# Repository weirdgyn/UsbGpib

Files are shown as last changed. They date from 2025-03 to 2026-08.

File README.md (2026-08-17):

# Table of contents

:newspaper: [Latest updates](Updates.md)
<br> :hammer: [Buy it or build it](#buy-it-or-build-it)
<br> :wave: [UsbGpib Introduction](#usbgpib-introduction)
<br> :house: [Housing / Enclosure](#housings)
<br> :computer: [Software](#software)
<br> &nbsp; &nbsp; :electric_plug: [Using the device](#using-the-device)
<br> &nbsp; &nbsp; :gear: [Setting and getting parameters](#setting-parameters)
<br> :heavy_check_mark: [Testing status](#testing-status)
<br> :notebook: [Tutorials](Tutorials/README.md) <- **New!**
<br> :heart: [Support the Project](#support-the-project)

# Summarized latest updates

For detailed visibility look under the Latest update link above!

[17h Aug 2026] Nice project: **[XyphroLabs-USBGpib-DMM4050](https://github.com/ZandanKhan/XyphroLabs-USBGpib-DMM4050)** — a Python GUI by [Zandan Khan](https://github.com/ZandanKhan) for controlling the Tektronix DMM 4050 (6½-digit precision multimeter) over UsbGpib, with measurement logging to CSV. Great example of building a full front-end on top of this adapter.

[17th Aug 2026]: **GPIBee is available, but...**

# GPIBee = UsbGpib V3 is available!

The title says it: GPIBee - UsbGpib V3 - is now available. Finally!  
  
It's for everyone who's told me, in issues and DMs, "I love this, but I don't have time to build one": USB-C and Ethernet with PoE, VXI-11 with multiple simultaneous sessions, and 3.5-5x the speed of V2 - in a proper enclosure, with real support behind it. 
It's built, tested, and shipping now.

I put together a short video showing it in action: [Introducing GPIBee](https://lnkd.in/epR7Xf-b).  
And you can find the full details at [GPIBee.com](https://www.gpibee.com).

This didn't come out of nowhere - there's a bit of a story behind it, including one thing I haven't said outright until now, something I went back and forth on for quite a while before deciding.

~7 years ago I started UsbGpib as a weekend project: An open, MIT-licensed way to talk to GPIB instruments without paying for an $800+ commercial adapter. I never expected it to pick up 642 stars, 82 forks, and end up soldered into home labs, universities, and repair benches around the world. That still means a lot to me, and it's the reason I kept and keep maintaining it for as long as I have.

A fair bit of that maintenance happened on evenings and weekends that would otherwise have gone to family time or just switching off. Nothing dramatic - just the normal trade-off of a side project that grew bigger than expected. Honestly, the part I'll remember most isn't the hours, it's the people: The issues, the emails, the odd late-night message or calls from someone debugging their own build. I've genuinely enjoyed those conversations, and they're a big part of why I kept going.

Along the way I also learned some harder lessons. To be clear, I've always been and are genuinely happy to see people or companies build their own UsbGpib - that's exactly what open source is for. What sat less well with me was seeing unrelated manufacturers turn V2 into a business of their own, selling it at scale with no attribution back to the project. That's a different thing entirely from working with official partners like Elecrow and Binho, who I have a real relationship with and who've supported this project properly.

But it stayed with me while I was figuring out what V3 should be, and it wasn't an easy decision to make.

So here's the thing I haven't said outright until now: V3 - GPIBee - is a commercial product rather than an open one. Something which might change in future, but for now it is.

That's a real change from V1/V2, and I don't want to gloss over it.

Here's the honest reasoning:

- Going commercial means there's a sustainable way to keep this going, rather than relying on whatever spare evenings I happen to have.
- It lets me fund the things a hobby project can't - CNC-machined, EMI-shielded enclosures, firmware QA, and proper support.
- It gives the project a legitimate path forward that undercutting clones can't quietly erase.

None of that changes what's already yours. V1 and V2 stay exactly as they are - MIT-licensed, fully open, schematics and firmware included, free to build and modify. And to be clear: I'm not walking away from it. I'll keep maintaining UsbGpib - answering issues, keeping it working - alongside GPIBee, not instead of it.

I'm proud of where this landed, and I'm looking forward to keeping both projects going - UsbGpib and GPIBee side by side. Thanks for seven years of bug reports and good conversations so far, with plenty more to come I hope. I hope some of you will give GPIBee a look, and either way, I'd genuinely love to hear what you think.

---

# Buy it or build it

* Tired of tinkering? Want to skip the hassle and get straight to using your GPIB setup?  
* You’d rather spend your time using your instruments instead of assembling hardware?

Skip the soldering iron and jump straight into your GPIB workflow!

You’ve got two solid options to get a ready‑to‑run UsbGpib adapter.

## &#x1f1fa;&#x1f1f8; - United States
* If you're in the US, you can now order the UsbGpibV2 directly from several sources, including my distribution partner Binho LLC. Enjoy fast domestic shipping with no long waits, no customs paperwork, and no surprises - just quick delivery and a smooth experience: 
<br> &#x1F449; <a href="https://binho.io/test-measurement/products/usbgpib-v2/" target="_blank">https://binho.io/test-measurement/products/usbgpib-v2/</a>
<br> &#x1F449; <a href="https://www.digikey.com/short/29nqq5cz" target="_blank"> https://www.digikey.com/short/29nqq5cz</a>
<br> &#x1F449; Amazon US also has it listed, but right now no stock, but worthwhile to check it out there too.

## &#x1F30E; - Worldwide
* I’ve teamed up with Elecrow to bring you ready-to-roll GPIB-USB converters – perfect for those who want results, not a weekend project.
* These adapters come fully assembled, programmed, housed, tested, and ready to go. No fuss. No build. Just plug it in and start working.
* The Adapters match 100% the V2 version described in this repository. 
* &#x1F449; <a href="https://www.elecrow.com/xyphrolabs-gpibusb.html" target="_blank">https://www.elecrow.com/xyphrolabs-gpibusb.html</a>

Let the data flow begin!

This doesn’t mean I’m going fully commercial - far from it.
Offering pre-built adapters is simply a convenience for those who’d rather skip the build and get straight to using their gear.

All sharing, support, and collaboration will remain fully open, just as before.
This is about choice, not change!

The full design files are located in this repository in case you want to build the devices yourself.

---

# UsbGpib Introduction
Versatile, cheap, portable and robust USB to GPIB converter (USBTMC class based).

You'll find many projects like this, but this one is special (ok, everybody will claim this) :-)

V1 Hardware: 


V2 Hardware: 


If you have a lot of test equipment at home, you might know the issues: Lots of devices only have GPIB as interface and the GPIB adapters and GPIB cables on the market are very expensive and some of them even have many issues, when run under Windows 10 (device driver does not work). Or they e.g. are not able to be operated with VISA, because they are UART based, need special command sequences, ...


The adapters are also typically very long, such that they extend the overall length of your test equipment by at least 10cm (~4 inches).

Apart of the 2 very big manufacturers, other GPIB adapters, e.g. with Ethernet or also USB interface are not recognized by normal VISA providers or PyVisa, making the measurement control implementation specific for your GPIB adapter.

I've got frustrated and tried to turn it into something positive. Here a video showing the final device in action - click to view:

(https://www.youtube.com/watch?v=pZp1QZCXrF8) 

Some goals of the project were:
- Work based on the standard USBTMC protocol. This allows the GPIB test equipment to look like a normal USB based measurement device and work flawless with e.g. NI VISA, Labview, Matlab or PyVisa.
- Have a small length - otherwise my equipment has the risk of falling from the shelf :-) Also the USB cable should connect 90 degree angled, to make it very short. With V2 HW, the length got further reduced to the size of a GPIB connector.
- It should be cheap but still versatile (you can build a single one of these for only 14 USD!)
- It should support ALL my test equipment, from many different GPIB implementation generations and different GPIB flavors
- The Firmware should be upgradeable over USB
- It should be rock-solid (!) I don't want to end up in a very long measurement being interrupted because of a software issue of my USB GPIB converter.
- It should support additional features like serial poll, remote enabling/disabling
- If there is no GPIB device connected to the USBGpib converter, or the GPIB device is powered down, there should be no USB device visible on the PC.

All those goals are met.

---

# Hardware

## Microcontroller choice

Although I typically would prefer nowadays an ARM Cortex M0/3/4/7 controller, there is an issue with it. Available devices support only max. 3.3V supply voltages, such that there would be a requirement for a level-shifter towards the GPIB Bus.
GPIB is based on 5V (not exactly true, but a first iteration).

This limited the microcontroller choice to e.g. AVR or PIC controllers. Because of very good availability I ended up in ATMEGA32U4 controllers.
Apart of the device supporting 5V I/O voltages, it also does not require a regulator to be part of the application - it has an internal 3.3V regulator. This minimizes the full application schematic and BOM.

Apart from that, there is an excellent USB stack available [http://www.fourwalledcubicle.com/LUFA.php](http://www.fourwalledcubicle.com/LUFA.php).

The GPIB side of the schematic can be directly connected to the ATMega32U4 IO pins. The IO pins from the microcontroller side are only set to 2 different states: Tri-state (input) or output LOW, to talk over GPIB.

## Component sourcing

All components are easy to source, so I only specify the potential critical ones:

- 16 MHz Crystal: Farnell 2853867 - MCSJK-7E-16.00-8-30-100-B-30 
- REV 1 GPIB connector: Farnell 2421095 - NORCOMP 112-024-113R001. For REV 2 use a straight 24P male solder type connector e.g. from AliExpress.
- USB connector for V1 HW: Farnell 2668483 - Amphenol ICC 61729-1011BLF
- USB connector for V2 HW: Best is to look on AliExpress for 57 series 24P connector as a starting point.

## PCB

The PCB can be ordered at nearly any PCB pool production service (e.g. 10 PCBs for 2 USD + shipping). The gerber files are included in the "HW/Gerber files" subdirectory.

## Mounting the PCB & Flashing the firmware

The PCB is available in 2 revisions.
- [REV 1](HW/REV1/README.md) is the most popularly used right now due to age. It has a USB Type-B connector and an L-shaped housing visible on a few photos of this page.
- [REV 2](HW/REV2/README.md) has some improvements like being smaller, better fit and USB Type-C connector.
- A REV 3 is upcoming. It will be a major redesign with more speed, Ethernet and power over Ethernet support, but the same DNA: Standard protocols being used and ensure compatibility and stability!

Choose whatever you prefer. The software images, but also the external behavior is the same.

---

# Housings

## REV 1


I created a sophisticated 3D printable housing for this adapter. The design was made with Fusion 360. The project file + the STL files are included in the "Housing" sub directory.

The PCB fits perfectly into it. Optionally it can be fixed with 2 mounting screws (the GPIB connector has 2 threads, use 2 times 4-40 UNC x 3/8) and the TOP cover snaps onto the housing base.

I printed this using an Ender 5 3D printer with black PLA, 0.15mm layer height, 1mm wall thickness, no support.
Take care, that you rotate the TOP part of the housing by 180 degrees, so that the flat side is located on the printer bed.
Printing works fine, several iterations of the design were made to ensure good printability.
I printed so far 15 housings, without a single fail.

More information on this REV 1 can be found here: [REV 1](HW/REV1/README.md).
Note, that also the programming/build instructions moved to this location.

## REV 2



The REV 2 housing is a lot smaller, but requires 2 screws.
The housing is quite important to be able to connect and disconnect the board without breaking anything. It is key for mechanical stability of the adapter.
When operating the device without housing, take very well care when plugging in and out the board in case the GPIB connector has a very tight fit.

Information on how to build it can be found in the HW/REV 2 folder: [REV 2](HW/REV2/README.md).
Note, that also the programming/build instructions moved to this location.

---

# Software

## Source code

The source code of the Boot loader (slightly modified LUFA MassStorage Boot loader) and the main USBGPIB converter are located in the "SW" subdirectory.
At the time of publication LUFA 170418 release was used, with GCC as compiler.

Note: The Software is compatible with any HW revision in this repository. For REV 1 and REV 2 hardware you don't need different SW images.

## Binaries

For those, that just want to create their own device, I've included the binary output in the "SW/binaries" subdirectory.

---

# Using the device

## USB enumeration

You might be surprised initially, that the device does not show up in your device manager (or lsusb), when you connect only the USB side. This is a feature, not a bug (really!).
Only, if a GPIB device is connected, you can see the device on your PC too.

The reason behind the feature is simple: Instead of having a standard GPIB wiring, where you have a single GPIB controller and lots of GPIB devices interconnected, USBGPIB supports only a direct connection of the USBGPIB device to your measurement device. If you have like me e.g. 14 Instruments you don't want all to show up in the device manager, if the measurement device itself is powered down - you won't anyway be able to communicate with a powered down device.

When USB and the GPIB side is connected, the device enumerates. The USBGPIB device reads out the ID of the instrument and constructs a unique USB Serial number out of it. It is thus easily possible to assiate multiple connected USBGPIB devices with the measurement instrument.

The VISA ressource name is constructed from this USB Serial number. You can identify easily e.g. in NiMax, which device is connected:



If you connect your USBGPIB device afterwards to another GPIB measurement device, it will disconnect and connect with a new serial number string, matching the other GPIB device *IDN? response again.

## GPIB settings on your measurement device

GPIBUSB does probe all GPIB primary addresses (and secondary address 0) for presence of a GPIB Talker/listener. It is thus not required to set a specific GPIB address - GPIBUSB will find it itself.

The only importance setting on the measurement device is, that the GPIB interface is enabled, which is typically the case.

## LED indicator

The LED indicates different states:

LED blinking: The USBGPIB converter is connected to a measurement instrument, it is powered off or its GPIB port is disabled. In this state, the device is also not connected to USB and will not show up in the device manager or lsusb.
LED on: The device is connected to a measurement device and GPIB communication possible. It is also accessible over USB
LED off: The device is not connected over USB, or the PC powered off :-)

## Controlling GPIB devices


As this converter implements the standard USBTMC Test and measurement class, you can control your instrument from ANY of the normal VISA tools. I tried so far R&S VISA and NI Visa, using Python and Matlab to talk to the devices.

# Testing status

This project is actively maintained since more than 6 years and I personally consider it as very stable. It is proven by multiple users to operate on MacOSX, Linux and Windows and measurement equipment from several decades.

In general I take bug reports very serious and want to "fix them all". In case you don't get an answer on-time on items you report in the issues section, please write me: Xyphro@gmail.com. 
I often miss seeing issue reports very quickly, as I don't get an email once they are filed.

## Sucessfully tested measurement equipment:

Below list is equipment I mainly myself tested. Many other users have other measurement equipment proven in use already.

- R&S FSEM30
- R&S SMIQ03
- R&S CMU200
- R&S SMW200A
- R&S FSW
- R&S FSV
- Keithley 199 multimeter
- HP 34401 DMM from different generations / with different FW versions
- HP 3325A synthesizer/frequency generator
- HP 3457A multimeter
- Agilent E4406A VSA transmitter tester
- Tektronix TDS7104 Digital Phosphor Oscilloscope
- HP 8596A spectrum analyzer
- Agilent E3648A dual power supply

A rather incomplete summary of equipment reported to work from users is:
- Keithley S46T
- HP/Agilent/Keysight 34401A of different generations
- HP/Aglient/Keysight 34410A
- Agilent N6700B
- Agilent E4416A
- Agilent 34970
- Keysight E3645A
- Keithley 2230G-30-1
- Keithley 2601A
- Tektronix AFG3102
- Tektronix 3014C
- Rohde & Schwarz SMB 100A
- Agilent E3631A
- ICS 4899GPIB
- TTI QL564TP
- Lecroy LW110
- LeCroy 334A
- LeCroy 354A
- Hameg 3524
- Fluke 5522A
- Fluke 5500A 
- and many more... It will take quite a while till I have parsed all my emails for working instruments :-)

## Scenarious

- It works under all popular operating systems like Windows 7 and 10, 11, Linux and MacOSX
- USB1.1, USB2.0 and USB3.x ports tested, with and without USB HUB in between.
- The connection stays responsive, when power cycling the PC, or hibernating/sleeping it
- Different connection cycles (GPIB side connected first, USB side connected first, swapping GPIB side equipment, ...)
- Extensive testing of timeout scenarious. E.g. making an illegal query and testing, if the USBTMC handles the timeouts properly. This was a very tricky part to get right.
- Tested special transfer modes. E.g. capturing screenshots from different equipment is usually something, which will drive other GPIB adapters to the limits, because binary data of unknown length needs to be transported successfully.

# Setting Parameters

The firmware version from 13th January 2024 onwards has the ability for human readable text base configuration of several parameters.
The previous methods are still supported, but won't be further documented. You can look them back in the history of this file.

The command parser is quite simple. For that reason follow the exact syntax as shown below. 
Don't add extra spaces or make other modifications or concatenate commands.

## Read termination method

While most GPIB interfaces use the hardware signal EOI to signal the end of a message, not all old equipment supports it. Some older instruments even don't have the EOI pin hardware wise wired and use \r or \n termination.

The USB-TMC standard allows to set the read termination. While in firmware versions before < 2.0 I did not enable that method, it is now finally supported with standard compliance.

I document here the older method (using pulse indicator request), but I add also the newer methods which are 100% UsbTmc compliant and portable across different equipments. You can choose which ones to use, but in some cases pulse indicator requests can be difficult to issue, for which reason it is likely better to use the standard compliant method.

### Set read termination to CR (\r):
(old method)
```
dev.control_in(0xa1, 0x40, 0, 0, 1); # USBTMC pulse indicator request (enables internal command processing)
dev.write('!term cr')
```
Above setting is volatile. To make this a permanent setting call the below mentioned "!term store" command.

(prefered method) Alternatively you can set the termination directly with visa means, e.g. using PyVisa:
```
dev.set_visa_attribute(visa.constants.VI_ATTR_TERMCHAR_EN, True)
dev.set_visa_attribute(visa.constants.VI_ATTR_TERMCHAR, ord('\r') )
```

### Set read termination to LF (\n):
(old method)
```
dev.control_in(0xa1, 0x40, 0, 0, 1); # USBTMC pulse indicator request (enables internal command processing)
dev.write('!term lf')
```
Above setting is volatile. To make this a permanent setting call the below mentioned "!term store" command.

(prefered method) Alternatively you can set the termination directly with visa means, e.g. using PyVisa:
```
dev.set_visa_attribute(visa.constants.VI_ATTR_TERMCHAR_EN, True)
dev.set_visa_attribute(visa.constants.VI_ATTR_TERMCHAR, ord('\n') )
```

### Set read termination to EOI only (default setting):
(old method) 
```
dev.control_in(0xa1, 0x40, 0, 0, 1); # USBTMC pulse indicator request (enables internal command processing)
dev.write('!term eoi')
```
Above setting is volatile. To make this a permanent setting call the below mentioned "!term store" command.

(prefered method) Alternatively you can set the termination directly with visa means, e.g. using PyVisa:
```
dev.set_visa_attribute(visa.constants.VI_ATTR_TERMCHAR_EN, False)
dev.set_visa_attribute(visa.constants.VI_ATTR_TERMCHAR, ord('\0') )
```

### Save readtermination setting in eeprom (make them non-volatile)
```
dev.control_in(0xa1, 0x40, 0, 0, 1); # USBTMC pulse indicator request (enables internal command processing)
dev.write('!term store')
```

Above relates to the "old non prefered method". In general it is a good idea to set the read termination volatile and use the above suggested methods highlighted with (prefered method).

### Query current termination setting from device
```
dev.control_in(0xa1, 0x40, 0, 0, 1); # USBTMC pulse indicator request (enables internal command processing)
print(dev.query('!term?'))
```
This returns a text string containing "lf", "cr" or "eoi"

## Multi-device support - Setting the GPIB device target address

Since Firmware version V2.4 USBGpib allows supporting multiple instruments.

While the USBTMC protocol allows only setting a single device to be addressed and composite USB devices are not well supported by all VISA implementations, I decided to add a command to set the address of the GPIB device which is addressed.

There is a minor limitation of this approach, which is that service request SRQ handling is only done properly to the currently selected GPIB device.
Another one is, that users shall never forget to set the GPIB address to the correct setting before issuing a command.

### Setting a primary address only

Substitute the text <Primary_address> with a number from 1 to 30 to set the primary address of the new GPIB device to talk to in following GPIB transactions

```
dev.control_in(0xa1, 0x40, 0, 0, 1);
dev.write('!addr <Primary_address>')
```

### Setting a primary + secondary address

Substitute the text <Primary_address> with a number from 1 to 30 to set the primary address and <Secondary_address> with a number from 0..6 or 96..102 of the new GPIB device to talk to in following GPIB transactions.
Note, that not the full subaddress range of 0..31 or 96..127 is supported as of now - this requires a bit more work. Most common device with subaddresses like R&S CMU200 only are well covered with that current range.

```
dev.control_in(0xa1, 0x40, 0, 0, 1);
dev.write('!addr <Primary_address> <Secondary_address>')
```
### Python wrapper example code for GPIB address setting

```
import pyvisa as visa
dev = 'USB0::0x03EB::0x2065::GPIB_22_14236333938351C00011::INSTR'
rm = visa.ResourceManager()
dev = rm.open_resource(dev, open_timeout=1000)

def set_gpib_addr(primary_address, secondary_address = None):
    dev.control_in(0xa1, 0x40, 0, 0, 1);
    if secondary_address is None:
        dev.write('!addr %d' % primary_address);
    else:
        dev.write('!addr %d %d' % (primary_address, secondary_address));
    
# Address CMU200, which is for me on primary address 1, secondary address 0
set_gpib_addr(1, 0)
print(dev.query('*IDN?'))

# address HP3457A on primary GPIB address 22
set_gpib_addr(22)
dev.write('END,ALWAYS')
print(dev.query('ID?'))
```

This code results in my current testsetup with CMU200 and HP3457A in this output:

```
Rohde&Schwarz,CMU 200-1100.0008.02,xxxxxx,V5.22

HP3457A
```

## AutoID setting

Default wise the GPIB adapter tries during power on of the instrument to query using *IDN? or ID? commands the instrument name automatically.
This is used to build the USB serial number, which finally gets part of the VISA ressource string.

Not all instruments support this *IDN / ID? query. For this reason this feature can be turned off.
The serial number will then be built based on the GPIB address of the instrument.

### Turn AutoID feature off
```
dev.control_in(0xa1, 0x40, 0, 0, 1); # USBTMC pulse indicator request (enables internal command processing)
dev.write('!autoid off')
```
This setting is stored in eeprom = non volatile memory, so will survive a power cycle

### Turn AutoID feature on
```
dev.control_in(0xa1, 0x40, 0, 0, 1); # USBTMC pulse indicator request (enables internal command processing)
dev.write('!autoid on')
```
This setting is stored in eeprom = non volatile memory, so will survive a power cycle

### turn auto ID on with delay

Some instruments need after turn on some seconds before GPIB is responsive.

With below 3 settings you can set a delay which is applied before the instrument ID is queried after power on.
Note that it will take then also more time, before the USB device is recognized by the PC.

Also this setting is non-volatile.

Delay 5 seconds:
```
dev.control_in(0xa1, 0x40, 0, 0, 1); # USBTMC pulse indicator request (enables internal command processing)
dev.write('!autoid slow')
```

Delay 15 seconds:
```
dev.control_in(0xa1, 0x40, 0, 0, 1); # USBTMC pulse indicator request (enables internal command processing)
dev.write('!autoid slower')
```

Delay 30 seconds:
```
dev.control_in(0xa1, 0x40, 0, 0, 1); # USBTMC pulse indicator request (enables internal command processing)
dev.write('!autoid slowest')
```

### read autoid setting

```
dev.control_in(0xa1, 0x40, 0, 0, 1); # 
print(dev.query('!autoid?'))
```
Returns as text string either: "off", "on", "slow", "slower" or "slowest".

## Firmware version

Finally I implemented a command to query the USB adapters firmware version :-)

```
dev.control_in(0xa1, 0x40, 0, 0, 1); # USBTMC pulse indicator request (enables internal command processing)
print(dev.query('!ver?'))
```

## Shorten ressource strings (Matlab)

A user discovered that Matlab has a limitation in the VISA ressource string length and shared a pull request to reduce the length.
I expose this now first time in the baseline firmware with the following options.

This setting is stored in eeprom = non volatile.

### Limit the USB serial number to a length of 20 characters
```
dev.control_in(0xa1, 0x40, 0, 0, 1); # USBTMC pulse indicator request (enables internal command processing)
dev.write('!string short')
```

### disable limitation of USB serial number length (default behavior)
```
dev.control_in(0xa1, 0x40, 0, 0, 1); # USBTMC pulse indicator request (enables internal command processing)
dev.write('!string normal')
```

### query the string length setting.
```
dev.control_in(0xa1, 0x40, 0, 0, 1); # USBTMC pulse indicator request (enables internal command processing)
print(dev.query('!string?'))
```

This returns as text string either "normal" or "short".

## reset the adapter
```
dev.control_in(0xa1, 0x40, 0, 0, 1); 
dev.write('!reset')
```

Do a reset of the adapter. Note that due to the reset you have to close the visa session and start a new one as the device re-enumerates on the USB.

---

# Support the project



Or support by buying a fully prebuilt adapter at: <a href="https://www.elecrow.com/xyphrolabs-gpibusb.html" target="_blank">https://www.elecrow.com/xyphrolabs-gpibusb.html</a>

In general any email, post or feedback is also very valuable, and don't feel bad if you don't use the support options :-)
Feel free to contact me at Xyphro@gmail.com

---

This page is from XyphroLabs UsbGpib project: <a href="https://github.com/xyphro/UsbGpib" target="_blank">https://github.com/xyphro/UsbGpib</a>

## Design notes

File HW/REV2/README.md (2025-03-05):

# xyphro UsbGpib HW REV 2

The new HW revision picks up some things that I and other misliked:
- The REV 1 HW - when put beeing assembled into its housing did have change to colide with parts of the instruments body. Especially for Keysight equipment. This new HW revision follows the formfactor of an original GPIB cable to get rid of this mechanical constraint.
- The REV 1 HW required to enter the bootloader with a tweezer. REV 2 has a button. Hold it a few seconds and the bootloader is entered.

The [software](../../SW) will always stay the same, no matter if REV1 or REV 2.

I have built many of those adapters myself so far and have developed trust in the design:


## Assembly process

All files related to HW are located in this folder. Gerber file, BOM, Kicad design files.

## preparing the PCB

Mount only the SMD components. This means: DON'T mount the GPIB connector yet.

On edge you can find a mounting point for a pinheader - 45 degrees angled. Mount 2-3 pin pinheaders here and you now have a 6 pin ISP programming port with standard pinout for your favorit AVR programmer.
Program the bootloader. Pin 1 is marked on the PCB to allow you connecting the ISP cable in the correct orientation.

### Flashing the Microcontroller first time

For initial programming an AVR ISP adapter is needed to program the "Bootloader.hex" file.

It is very important, that the Fuses of the AVR are programmed.

Here an example how to program the bootloader using avrdude (using usbasp programmer):
```
avrdude -c usbasp -p m32u4 -e -Ulock:w:0xFF:m -Uefuse:w:0xcb:m -Uhfuse:w:0xd8:m -Ulfuse:w:0xde:m
avrdude -c usbasp -p m32u4 -U flash:w:BootLoader.hex
```
To program bootloader and application image at the same time using AvrDude, you can use this command:
```
avrdude -c usbasp -p m32u4 -e -Ulock:w:0x3F:m -Uefuse:w:0xcb:m -Uhfuse:w:0xd8:m -Ulfuse:w:0xde:m -U flash:w:TestAndMeasurement.hex -U flash:w:BootLoader.hex
```
Note, that some programmers use a quite high clock frequency on the programming interface. In case of failures try to decrease the SCK clock frequency!

After programming the file, disconnect and connect the device and a USB drive will show up. Copy the TestAndMeasurement.bin file to this USB drive - ideally using the command line. Example: `copy TestAndMeasurement.bin F:\FLASH.BIN`.
On Linux, there is a bug with the LUFA mass storage that means it is required to use `dd if=TestAndMeasurement.bin of=/mnt/FLASH.BIN bs=512 conv=notrunc oflag=direct,sync`.

When done, disconnect USB.

It is now safe to desolder the ISP pinheaders such that the PCB fits into the housing. 
Any further update can happen over USB using the bootloader.

## Building the whole thing together
Preparation:
- Mount the PCB EXCLUDING the GPIB connector.
- Print the housings located in [this folder](../../Housing/Rev2). I print them using 1mm bottom/top/wall thickness, 0.16mm layer height and 30% infil. On my K1 printer it takes 23 minutes to print, on my Ender 5 2.2 hours.
- get 2 20mm M3 screws and 2 M3 nuts
- get a GPIB connector "24P Male solder type" from e.g. Aliexpress

If you have everything in place and prepared, insert the PCB including the GPIB connector (unsoldered!) into the bigger part of the housing:



Then solder 2 pins of the GPIB connector and take the PCB out of the housing again to solder all pins.
(This step is required to ensure that the GPIB connector has the right distance to the PCB and fit into the housing)

As a next step insert the PCB into the big part of the housing again. It has a relatively tight fit - to ensure mechanic stability.

Then put the smaller part of the housing on top of it, insert the screws (they can be pushed hard to destroy the "membrane" first time) and nuts and screw it together.

Voilà... your adapter is finished and ready to use :-)



# Updating the firmware at later stages

To enter the boot loader at later stages for updates, press the button (bigger hole in the housing) using a pen/paperclip for about 3 seconds. Then a USB mass storage (flash drive) enumerates on the PC where the firmware image can be copied too (see previous chapter).

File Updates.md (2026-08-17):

This new file will in future contain all updates. The latest updates are always on top.

# Recent Updates

## 17th Aug 2026

UsbGPIB V3 = GPIBee is available - see: https://www.gpibee.com/

Have also a look at this nice project:  
**[XyphroLabs-USBGpib-DMM4050](https://github.com/ZandanKhan/XyphroLabs-USBGpib-DMM4050)** — a Python GUI by [Zandan Khan](https://github.com/ZandanKhan) for controlling the Tektronix DMM 4050 (6½-digit precision multimeter) over UsbGpib, with measurement logging to CSV. Great example of building a full front-end on top of this adapter.

## 09th June 2026

Devin (W6DVN) has successfully ported the popular KE5FX GPIB Toolkit to work seamlessly with UsbGpib V2. You can find the updated version here: https://github.com/fehknt/GPIB

KE5FX GPIB toolkit is a popular set of specialized GPIB applications created by John Miles to make research-grade measurements using oscilloscopes, spectrum analyzers, counters and other IEEE-488 instruments.

## 18th April 2026

USBGpib has now support to address multiple GPIB devices with the newly added firmware version V2.4.

Similar to some UART based GPIB controllers a command is added to set the GPIB address of the device to talk to.

Look for "Multi‑device support" in [README.md](README.md) for more details and instructions.

## Multi-device support - Setting the GPIB device target address

## 07th March 2026

Chinese New year struck in and just shortly before it UsbGPIB V2 ran out of stock. Fortunately it is now back in stock and ready to order again!

## 04th February 2026

The PDF manuals are now also available in Markdown, generated automatically from the same source as the PDF document. This makes the documentation easier to browse, diff, and maintain in version control, while ensuring both formats stay perfectly in sync. -> See [Tutorials](Tutorials/README.md) section.

Furthermore I am releasing Firmware version V2.3. 
Changes:
- It turned out that Keysight Visa in certain versions can crash when a USBTMC device has a serialnumber with double underscore characters. Note, that the USBTMC standard does not disallow for double underscores. The AutoID function can return double underscores for some instruments - illegal characters returned by *IDN? query get replaced by underscores, so with 2 illegal characters you get double underscores as serial number = visa ressource name. I've now included a filter now to suppress double underscores when autoid is enabled.
- I've fixed Issues #96 and #97 reported by user thewon86. Those were USBTMC protocol issues which were never uncovered or effects seen so far, however the implementation was indeed incorrect here.

I updated also slightly the V3 announcement in the main README.MD. Basically: Firmware is ready for betatesting, Hardware arriving soon and gets distributed immediately once it arrives (@Betatesters: You'll get mail before shipping)!

My US distribution partner <a href="https://binho.io/" target="_blank">binho</a> also added UsbGPIB directly to their webshop (<a href="https://binho.io/test-measurement/products/usbgpib-v2/" target="_blank">https://binho.io/test-measurement/products/usbgpib-v2/</a>). This is ideal for US-market: Devices ship directly from San Francisco and are available for a good price! Checkout also their offerings on Host adapters and PCBite!

## 30th December 2025

Updated the "Buy it or build it section" and added a Digikey US link for buying the adapter.

## 30th November 2025

**Just released a new firmware after testing - version 2.2.**

Changes:
* Read termination related:
  * When the "USBTMC native" method to set the termination was once enabled, disabling it did not have effect anymore - it stayed enabled. Only power cycling got it out of that enabled state. Fixed and tested now.
  * Only \n \r and EOI only were supported read terminations. However, as reported in <a href="https://github.com/xyphro/UsbGpib/issues/85" target="_blank">issue 85</a>, there is quite a number of measurement equipment which requires e.g. ETX (0x03) read termination.  
  I removed now this artificial limitation for read termination, such that any read termination character can be set. From 0x00 to 0xff all codes are supported now.  
  For the eeprom non-volatile based method only \r \n and eoi only options are available and there is no plan to extend it to any termination character as this eeprom based method will also get retired for the upcoming V3 UsbGpib adapter.
* GotoLocal synchronization. USBTMC uses 2 different transfer methods for transfering certain types of messages. Control transfers and Bulk transfers. When e.g. sending a USBTMC command like Reading data which uses Bulk transfers followed by another one like GotoLocal which uses control transfers it is important that they also get executed in that order.   
This is something I took deep care off already since long time for other other control transfers, however as it turned out never tested for GoToLocal.   
And things that are not tested don't work, right?   
Michael discovered this during porting of his <a href="https://github.com/VK2BEA/HP8753-Companion" target="_blank">HP8753-Companion</a> to support the UsbGpib V2 adapter which led to me releasing V2.1 to him a while ago.

The issue is fixed now and confirmed working. This V2.2 includes the 2 additional improvements now.

Next release is planned to cover some good improvements I got suggested on AutoID handling.

## 23rd November 2025

I just finalized a user manual for the UsbGPIB V2 adapter, checkout [Tutorials](Tutorials/README.md) section.

In case you miss certain aspects and want me to add them, let me know (Discussion section, Issue section or email to xyphro@gmail.com)

## From Bench to Ready: Buy It, Plug It, Use It!

Tired of tinkering? Want to skip the hassle and get straight to using your GPIB setup?
* I’ve teamed up with Elecrow to bring you ready-to-roll GPIB-USB converters – perfect for those who want results, not a weekend project.
* These adapters come fully assembled, programmed, housed, tested, and ready to go. No fuss. No build. Just plug it in and start working.
* The Adapters match 100% the V2 version described in this repository. 

**Grab yours now:** <a href="https://www.elecrow.com/xyphrolabs-gpibusb.html" target="_blank">https://www.elecrow.com/xyphrolabs-gpibusb.html</a>

Let the data flow begin!

This doesn’t mean I’m going fully commercial - far from it.
Offering pre-built adapters is simply a convenience for those who’d rather skip the build and get straight to using their gear.

All sharing, support, and collaboration will remain fully open, just as before.
This is about choice, not change!

## Coming soon: Native Linux-Gpib support
<small>(Or actually: It's already there!)</small>

A contact with the Linux-Gpib maintainer resulted in a great cooperation with good outcome. We managed to jointly get native linux-gpib support up and alive. Thanks a lot for that, Dave!

We’ve successfully brought full Linux-GPIB compatibility to life. To enable it, you’ll need to flash a dedicated firmware image:  
- File "LinuxGpib.bin" in sub-folder [LinuxGpib firmware](SW/binaries/) will enable it from firmware perspective. Note: This will make the adapter stop from enumerating as normal usbtmc device (you can reflash the normal firmware again later if you like). The upcoming adapter announced a few days ago will have a combined firmware, but the flash of AtMega32U4 was simply "too full".

Stay tuned — I’ll be publishing a detailed guide soon, covering setup instructions and the powerful benefits of going native on Linux.

Just to avoid misunderstandings: The Adapter always worked under Linux as normal UsbTmc device as it does on any other operating system, but was not supported by the Linux-GPIB library so far. So software packages using linux-GPIB can be used without modification in future.

Would btw. love to get similar integration also in Visa Libraries - let's see what time will bring :-)

## Update on Beta Tester program on new upcoming "V3" Adapter with Ethernet+PoE + High speed USB

I managed to find a decent amount of betatesters for the new upcoming HW. Much more as the originally anticipated 3 persons. Thanks a lot for all who volunteered! 



<small>Status: From the HW side the Ethernet and PoE section is tested successfully. USB was already enabled since long time.
SW side: The USB functionality is fully implemented and first stress testing shows positive results with no lockups. The Ethernet stack is up and running too, but further implementation and testing work is still to be done.</small>

# 21st April '25 update

Today it's time for another release - version V2.0. 

While writing this and looking at this readme.md file, I certainly think that I should clean it up in future - it is not well structured for new users. Sorry for this, but I have this on my radar and will improve. Whenever I have more time I will also extend it with usage examples / small "trainings", especially for those who are completely new to GPIB and controlling instruments.

I had btw. some occasions where users had issues flashing the device. Many of them were caused by the fact that the .hex and .bin files were saved over the GitHub web interface by rightclicking and selecting "Save as". This will result in a HTML page being saved which will not flash well :-)
The safest option is to do a git clone or to download this whole github repository as .zip file.

Here the release V2.0 details:
- **Bugfix:** the options autoid slower and autoid slowest did not work. This is addressed and I test those settings now also properly in release testing, promised :-) The issue was caused in my super slim parser implementation for custom internal commands and "autoid slow" and "autoid slower" start with the same letters causing hickups.
The Windows GUI is also updated to expose those 2 autoid settings - they were not included before.
As general good recommendation, I still recommend to turn autoid feature off, as it limits the measurement instruments which are used - Instruments HAVE to support *IDN? query for it to work well, which is for many old equipment not the case and for such old equipment errors will be flagged after the instrument is turned on.
- **New feature:** I enabled a new method to set the READ termination. One that is fully compliant with usbtmc standard and does not need a workaround with pulse indicator requests. I don't know why I did not spot this earlier, but a discussion with the usbtmc linux kernel mode driver maintainer exposed this to me. When using direct access to usbtmc kernel mode driver you can use the <a href="https://github.com/dpenkler/linux-usbtmc?tab=readme-ov-file#ioctl-to-control-setting-eom-bit" target="_blank">USBTMC_IOCTL_EOM_ENABLE</a> IOCTL to set the read termination. When using a VISA layer, you can set the read termination by setting the VI_ATTR_TERMCHAR_EN and VI_ATTR_TERMCHAR attributes (see below for more details). 
The previous method of setting read termination is not modified in any way, this just gives an additional method to set the readtermination.
- **Bugfix / Improvement:** The pulse indicator request function did use a blocking delay to pulse the LED. This delayed USB side handling. In some cases this could trigger timeouts. The LED blinking is now handled fully asynchronous and those timeouts will not occur anymore.

# 6th April '25 update

Time to release a bugfix (reported by rapgenic #80): V1.9 of the firmware fixes an issue where the "autoid slow" setting was not applied properly.

# 12th January '25 update

## New Gui available! (Windows)

I implemented a small GUI to change the non-volatile settings of the GpibUSB adapter. Sorry - it's windows only :-)
It is a single .exe file without external dependencies. You can just download it, run it and immediately change settings.



Please download it from this folder: [SW/UsbGpibGUI](SW/UsbGpibGUI)

The source code is included in the src sub-directory.

## Python GUI (Linux)

UsbGpib user Jim Houston created an impressive pure Python GUI similar to mine - and I believe he began working on it even before I released mine. His GUI stands out for its versatility and platform independence, requiring only Python to run. It can be executed directly with Python 3 and should run on most platforms.

For details about it, have a look into this discussion thread: [https://github.com/xyphro/UsbGpib/discussions/55](https://github.com/xyphro/UsbGpib/discussions/55)

The GUI can be found here including documentation: [SW/NiceGUI](SW/NiceGUI)

## New Firmware

I release also herewith Version 1.8 of the firmware. 
Mainly a bug-fix was done, that the string setting now also returns short, when it is actually set to short. (issue report #59).

# 13th January '24 update

New year, new update :-)

I realized a user suggestion, which is a better human readable interface to the internal instrument settings.
This also exposes new functionality, e.g. shortening of the visa resource string, adjustable delayed application of AutoID featured, ...
The read termination setting can now be set in a volatile way and also be read back.

A slight issue sneaked in also and got fixed: After an instrument clear the next GPIB transfer timed out. Nobody found it so far though :-) But I fixed it.

Have fun using this!
(would anybody volunteers to make a simple cross platform gui for the non volatile settings :-) ?)

# 19th December '23 update

Finally I made it - the new HW design is on this page. As I had to restructure the repository a bit it took quite a while.
The software image is always the same and runs on both HW revisions.



I also have put a binary for a new Firmware image in there. I am still busy optimizing certain things but want to give you a try before doing a next release.
Please if you test it: Feed it back to me - does it work / does it break anything -> sharing is caring. 

Mail me at xyphro@gmail.com or raise an issue under the issue section.

[FW image location: SW/binaries](SW/binaries)

- 488.2 support further rolled out. This means Status bytes are automatically read out and reported via interrupt transfers to PC as foreseen in the standard.
- FASTER (!) 7 x write speed improvement and 4.x times read speed improvement. As reference: On an FSW I get 310kBytes/s as write transfer speed and 240kBytes/s as read transfer speed.
- a fix for read status byte readout leading to issues on my CMU200
- several smaller race conditions identified and fixed. A lot of work went into stress testing 488.2.

As said, I feel this is the best Firmware image so far, but I changed so much that I want to go first for this small beta test phase asking you explicitly for positive and negative feedback.

---

This page is from XyphroLabs UsbGpib project: <a href="https://github.com/xyphro/UsbGpib" target="_blank">https://github.com/xyphro/UsbGpib</a>

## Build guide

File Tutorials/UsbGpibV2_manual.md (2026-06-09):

- [XyphroLabs UsbGpib V2 User
  Manual](#xyphrolabs-usbgpib-v2-user-manual)
- [Introduction](#introduction)
- [Advantages of UsbGpib V2 adapter](#advantages-of-usbgpib-v2-adapter)
- [Safety Precautions](#safety-precautions)
  - [Operating Conditions](#operating-conditions)
  - [Storage Conditions](#storage-conditions)
  - [Moisture & Contaminants](#moisture-contaminants)
  - [Electric Safety](#electric-safety)
  - [Handling & Installation](#handling-installation)
- [Overview](#overview)
- [LED](#led)
- [Using the adapter](#using-the-adapter)
- [Firmware update procedure](#firmware-update-procedure)
- [Technical specifications](#technical-specifications)
- [Frequently Asked Questions](#frequently-asked-questions)
- [References](#references)

# XyphroLabs UsbGpib V2 User Manual

Last Update: 9th June 2026  
This document is part of [Xyphro
UsbGpib](https://github.com/xyphro/UsbGpib) project

Prefer PDF? Click here:
[](UsbGpibV2_manual.pdf)  
Note: Click on the download RAW button on top right when viewing the PDF
online.

# Introduction

The UsbGpib V2 is a compact, high-performance USB-to-GPIB adapter
engineered from the ground up for seamless integration with modern and
legacy test equipment.

Unlike clone devices, UsbGpib V2 delivers robust IEEE-488.1 and
IEEE-488.2 compatibility, stable USBTMC operation, and a unique device
identifier that ensures consistent VISA resource naming across systems -
eliminating the need for manual remapping or COM port assignments.

Designed to match the physical footprint and cable path of traditional
GPIB connectors, the adapter fits into all existing lab setups while
offering significant advantages in space efficiency, cable management,
and cross-platform support. Whether you’re automating instrument control
on Windows, macOS, Linux, or FreeBSD, UsbGpib V2 provides plug-and-play
reliability without proprietary drivers.

With firmware upgradability, protocol-aware communication, and a focus
on user-friendly integration, UsbGpib V2 is the ideal choice for
engineers, researchers, and developers seeking a dependable GPIB
interface that just works.

# Advantages of UsbGpib V2 adapter

- Modern Connectivity: Bridges USB and IEEE 488 (GPIB) with full USBTMC
  protocol compliance

- Slim Design: Minimal depth of just 1.5cm allows instruments to be
  placed closer to walls or rack panels

- Cable Efficiency: Uses thin USB cables instead of bulky "garden hose"
  GPIB cables, reducing clutter and improving portability

- Multi Adapter Support: Unique identifier per unit enables multiple
  adapters to be connected and operated reliably on the same PC

- No COM Ports: Avoids serial port mapping issues; Each adapter is
  consistently accessible with the same name across multiple PCs

- Transparent Operation: Plug into your instruments GPIB port and it
  behaves like a modern USB measurement device, including proper USB
  port deactivation when the instrument is powered off

- Controller Role: Optimized as a dedicated GPIB controller for one
  instrument per adapter, ensuring robust one to one communication and
  optimized cable management.

- Standards Compliance: Implements full IEEE-488.1 IEEE 488.2 controller
  support via USBTMC, including status byte reading, triggering, service
  requests, and termination settings

- Software Compatibility: Works seamlessly with all standard VISA
  providers (NI VISA, Rohde & Schwarz VISA, Keysight VISA)

- Tool Integration: Fully compatible with LabVIEW, MATLAB, PyVISA, and
  PyVISA py for established and modern automation workflows

- Cross Platform Support: Operation across Windows, macOS, FreeBSD, and
  Linux

- German Engineering: Designed and developed in Germany over six years,
  extensively tested for robustness and compatibility with instruments
  from new to decades old

- Reliability: Built to ensure long automated measurement sequences
  complete without interruption

- Future Proof: Firmware is field upgradable and actively maintained,
  providing ongoing improvements and compatibility updates

# Safety Precautions

To ensure reliable operation and long-term durability of the UsbGpib V2
adapter, please observe the following environmental and handling
Guidelines

## Operating Conditions

| | |
|:---|:---|
| Temperature Range: | 0°C to +50°C |
| Humidity: | 10% to 90% RH, non-condensing |
| Altitude: | Up to 2000m above sea level |

## Storage Conditions

| | |
|:---|:---|
| Temperature Range: | -20°C to +70°C |
| Humidity: | 5% to 95% RH, non-condensing |

## Moisture & Contaminants

- Avoid exposure to liquids, vapors or corrosive substances

- Do not operate in environments with condensation, high dust levels or
  chemical fumes

## Electric Safety

- Do not expose to voltage levels above 6V

- Do not short circuit or connect to non IEEE488 / non-USB compliant
  ports

- Ensure proper grounding of connected instruments

## Handling & Installation

- Do not bend or stress the USB or GPIB connectors during installation

- Avoid excessive force when plugging/unplugging

- Avoid direct sunlight

- Keep away from electrostatic discharge (ESD) sources; use ESD-safe
  handling procedures

# Overview

<table>
<tbody>
<tr>
<td style="text-align: left;"><br />
</td>
<td style="text-align: left;">(1) GPIB connector - Plugs directly into
your measurement equipments GPIB port.</td>
</tr>
<tr>
<td style="text-align: left;"><br />
</td>
<td style="text-align: left;">(2) Status LED<br />
(3) Firmware update button</td>
</tr>
<tr>
<td style="text-align: left;"><br />
</td>
<td style="text-align: left;">(4) USB-Type C connector - plug it with
either a USB Type C to USB type A or USB type C to type C cable into
your PC.</td>
</tr>
</tbody>
</table>

# LED

The LED has multiple purposes as summarized in the table below.

<table>
<tbody>
<tr>
<td style="text-align: left;"><br />
</td>
<td style="text-align: left;">The Adapter is connected to a USB port,
but no GPIB device is found. Connect a GPIB measurement device to the
GPIB port and ensure that GPIB is enabled in the instrument.</td>
</tr>
<tr>
<td style="text-align: left;"><br />
</td>
<td style="text-align: left;">The GPIB device was identified, but no
GPIB communication is executed from PC.</td>
</tr>
<tr>
<td style="text-align: left;"><br />
</td>
<td style="text-align: left;">Every time GPIB data is transferred from
the PC or to the PC, the LED will be turned off for short periods of
time. This indicates data exchange = activity.</td>
</tr>
<tr>
<td style="text-align: left;"><br />
</td>
<td style="text-align: left;">The USB port is not connected to the PC,
the PC powered off or the USB cable defect.</td>
</tr>
</tbody>
</table>

# Using the adapter

To use the adapter, connect the USB-C connector with a USB cable to a
PC.

The GPIB connector can be plugged directly into the measurement
instrument, which you want to control. It can also connect via a GPIB
cable if required due to setup constraints.

When the measurement equipment is turned on and if the GPIB port is
enabled in the instrument, the adapter will enumerate on the PC as
USBTMC class device.

Operating system specific instructions & tutorials are available under
this link:

<https://github.com/xyphro/UsbGpib/blob/master/Tutorials/README.md>

Those tutorials explain how to ensure that a USB driver is installed and
guide through the first setup up to the point where you can talk with
the instrument.

<div class="tcolorbox">

Note: The UsbGpib Adapter does not enumerate on the PC, if it is not
connected to a GPIB measurement device, which is powered and GPIB
enabled.

</div>

# Firmware update procedure

The UsbGpib V2 adapter comes preinstalled with a firmware. But as the
firmware is actively maintained you might want to update the adapters
firmware sooner or later. The UsbGpib V2 adapter allows for firmware
updates. It requires the bootloader mode to be entered, followed by
programming the firmware and power cycling the adapter.

Firmware images are distributed via GitHub:

<https://github.com/xyphro/UsbGpib/tree/master/SW/binaries>

to download, left-click on "TestAndMeasurement.bin" file. After the new
page loads, click on the RAW button on the top right side:



After downloading the file, rename it to FLASH.BIN. Ensure to use
capital letters for the full filename during rename. Filenames with
lowercase letters like "Flash.bin", "flash.bin", "FLASH.bin" will result
in the firmware update procedure not to work (but it won’t break the
adapter).

After downloading the file, enter the bootloader:

- Connect the adapter to a PC via USB. The GPIB side can be left
  unconnected.

- Hold the button (3) down for a few seconds (use e.g. a pencil to push
  it), until the PC recognizes a memory stick device (USB flash or mass
  storage device).

A new drive appears on the PC:



Then open a command line and enter a command like the following:



<div class="tcolorbox">

On Linux, use this command to transfer a firmware update, instead of
using cp:
`dd if=TestAndMeasurement.bin of=/mnt/FLASH.BIN bs=512 conv=notrunc oflag=direct,sync`

</div>

Adjust the file paths and drive letters to your actual system. When no
error is shown, you can unplug USB (and GPIB) and reconnect to power
cycle the adapter and use the new firmware.

<div class="tcolorbox">

Note: Drag and drop operation e.g. from Windows explorer does not work.
Ensure you use the command line method as described.

</div>

<div class="tcolorbox">

Note: In case the device behaves as if it is bricked (which can happen
if you use cp under linux to reflash it), you can enter the bootloader
mode by unplugging the USB cable, keeping the button pressed and
connecting it again while holding the button.

</div>

# Technical specifications

<table>
<thead>
<tr>
<th style="text-align: left;"><strong>Item</strong></th>
<th style="text-align: left;"><strong>Specification</strong></th>
</tr>
</thead>
<tbody>
<tr>
<td style="text-align: left;">USB power requirements</td>
<td style="text-align: left;"><ul>
<li><p>5V supply voltage nominal</p></li>
<li><p>Valid supply voltage range: 4.5V to 5.5V</p></li>
<li><p>100mA current consumption</p></li>
</ul></td>
</tr>
<tr>
<td style="text-align: left;">USB standard</td>
<td style="text-align: left;"><ul>
<li><p>USB 1.1, USB 2.0, USB 3 and higher are supported with full speed
mode</p></li>
</ul></td>
</tr>
<tr>
<td style="text-align: left;"></td>
<td style="text-align: left;"></td>
</tr>
<tr>
<td style="text-align: left;">USB connector</td>
<td style="text-align: left;"><ul>
<li><p>USB Type-C connector</p></li>
<li><p>Compatible with USB-A by using a USB Type C to USB Type A
cable</p></li>
<li><p>Compatible with USB Type C to USB Type C cable.</p></li>
</ul></td>
</tr>
<tr>
<td style="text-align: left;">Supported IEEE-488 features</td>
<td style="text-align: left;"><ul>
<li><p>IEEE-488.1, IEEE-488.2, HPIB, GPIB compatible</p></li>
<li><p>Service request (reported using interrupt transfers)</p></li>
<li><p>Device Clearing</p></li>
<li><p>Trigger</p></li>
<li><p>Status Byte read</p></li>
<li><p>GPIB write, read and queries<br />
(supports talker only, listener only and talker+listener
instruments)</p></li>
<li><p>Full timeout support for reliable operation</p></li>
<li><p>All GPIB features are exposed using the exact USBTMC equivalents
for good compatibility</p></li>
</ul></td>
</tr>
<tr>
<td style="text-align: left;">Supported IEEE-488 device roles</td>
<td style="text-align: left;"><ul>
<li><p>Controller</p></li>
</ul></td>
</tr>
<tr>
<td style="text-align: left;">Operating Systems</td>
<td style="text-align: left;"><ul>
<li><p>Windows</p></li>
<li><p>Linux, FreeBSD</p></li>
<li><p>Mac-OS</p></li>
</ul></td>
</tr>
<tr>
<td style="text-align: left;">Dimensions</td>
<td style="text-align: left;"><ul>
<li><p>Excluding GPIB connector:<br />
  60mm x 23mm x 15mm (Width x Height x Depth)</p></li>
<li><p>Including GPIB connector:<br />
  60mm x 23mm x 22mm (Width x Height x Depth)</p></li>
</ul></td>
</tr>
<tr>
<td style="text-align: left;">Weight</td>
<td style="text-align: left;"><ul>
<li><p> 30g</p></li>
</ul></td>
</tr>
</tbody>
</table>

# Frequently Asked Questions

**Why doesn’t the adapter show up on my PC when I plug it in?**  
This is a feature called "Ghost Mode." The adapter only enumerates
(becomes visible) on the PC if it is connected to a GPIB instrument that
is powered on. This reduces device manager clutter when you have
multiple adapters connected to instruments that are currently off.

The reason for this feature is to make an instrument behave like one
with native USB interface and avoid seeing adapters on the PC with that
you can’t communicate anyway as there is no measurement equipment
connected.

------------------------------------------------------------------------

**What is the AutoID feature of UsbGpib V2?**  
AutoID is a feature where the adapter automatically queries the
instrument for its identity (using \*IDN?) and uses that information to
create a unique VISA resource name. For very old instruments that do not
support \*IDN?, this feature should be disabled to avoid errors. When
Auto ID is off, the Visa ressource name is constructed out of the GPIB
address of the instrument and a unique serial number of the GPIB
adapter.

------------------------------------------------------------------------

**What are the AutoID timing options?**  
When the AutoID feature is enabled there are different delay options.
This delay specifies how long the adapter waits after instrument turnon
before executing the \*IDN? query for the AutoID feature. While 5s works
for each instrument, some instruments require a setting to higher number
which is exposed by the other AutoID settings. AutoID is a non-volatile
setting which is permanently stored in the MCUs eeprom. **UsbGpibGui**:

- **AutoID ON:** The adapter waits 5 seconds after detecting a powered
  GPIB instrument before performing the identification scan `*IDN?`.

- **AutoID SLOW:** Increases the initial waiting period to 15 seconds
  before the scan begins.

- **AutoID SLOWEST:** Designed for instruments with very long boot
  sequences, this setting waits 30 seconds before attempting to
  communicate on the GPIB side.

- **AutoID OFF:** Disables the automatic identification query entirely.
  This is essential for older, non-SCPI instruments that do not support
  the `*IDN?` query and might return errors or lock up if they receive
  it.

**Tip:** Turn AutoID OFF for older non SCPI compliant instruments to
avoid that they start up with an Error. To change the AutoID settings
you can use e.g. the UsbGpibGui in the UsbGpib SW folder for Windows or
NiceGui for Linux. Note that UsbGpib GUI requires a Visa installation.

------------------------------------------------------------------------

**How do I set Read Termination?**  
It is best to use standard VISA attributes:

- Set `VI_ATTR_TERMCHAR_EN` to 1.

- Set `VI_ATTR_TERMCHAR` to `0x0A` (or any other ASCII character).

With firmware version $`\ge`$ 2.2 you can set any read termination
character you like, from ASCII code 0 to 255. This enables instruments
to react on EOT, CR, LF or any other character like e.g. ’,’ for easier
parsing of input data. Independent of the set termination character
setting the instrument will always react on the GPIB EOI as termination
of a read query.

When read termination is turned off, the read termination is EOI only.

------------------------------------------------------------------------

**Is the UsbGpib adapter a clone of an existing commercial adapter?**  
No. This is a common and important misconception. The UsbGpib adapter is
a completely original, open-source hardware and software project and
does not copy commercial adapters. It works for that reasons without
risk of getting blocked or locked out in future.

- **Unique Identity:** Unlike the many inexpensive adapters found on
  online marketplaces, this is **not** a counterfeit clone of National
  Instruments (NI), Keysight or other hardware.

- **Safe to Use:** Because it is not a clone, it is safe from "driver
  sabotage." Vendor software updates (like those from NI-VISA) often
  detect and disable counterfeit hardware; since this adapter uses its
  own independent firmware and identity, it remains fully functional and
  stable regardless of official driver updates.

- **Standard Compliance:** Instead of mimicking a proprietary device, it
  implements the standard **USBTMC-USB488.2** protocol. This allows it
  to "nicely integrate" into any VISA environment by following industry
  standards rather than exploiting a specific manufacturer’s driver.

In short: It is an independent, professional-grade tool designed to
coexist peacefully within the ecosystem of your choice.

------------------------------------------------------------------------

**Does it support Service Requests (SRQ)?**  
Yes, the adapter actively pushes SRQ signaling to the PC via an
interrupt pipe, as mandated by the USBTMC 488.2 standard. This means
your software does not need to poll for status continuously.

------------------------------------------------------------------------

**Can I use it with Linux?**  
Yes, it can be used either as a standard USBTMC device or through
Linux-GPIB for advanced features like controlling multiple instruments
with a single adapter. In case you want to use Linux-GPIB, have a look
here and search for "xyphro" for further instructions:
[<https://linux-gpib.sourceforge.io/doc_html/supported-hardware.html>](https://linux-gpib.sourceforge.io/doc_html/supported-hardware.html)  

------------------------------------------------------------------------

**Do I really need to use a VISA library?**  
Technically, no-but it is highly recommended. Because the adapter
follows the standard **USBTMC** protocol, it is natively recognized by
modern operating systems. Visa, while it seems like an "old-school
concept" is a quite convinient tool to enable access to instruments over
multiple different interfaces with a common interface.

I started e.g. by controlling only USBTMC instruments and made a
dedicated solution for that without visa, but when I later wanted to
control GPIB instruments and Ethernet based instruments in the same
setup, that "island solution" concept breaked and I started looking
seriously into Visa and saw the clear benefits. Don’t get shocked by
Gigabytes of Visa installation - there are smaller Visas available like
e.g. R&S Visa. Lean and mean and available for Mac OS, Windows, Linux
and even Raspberry PI with the same application level interface across
those operating systems. You also get a very stable tested solution for
your instrument access and can focus on the real measurement task.

- **With VISA:** Libraries like *R&S VISA* or *NI-VISA* provide a
  unified API. This is the most stable path for tools like LabVIEW or
  standard `PyVISA`.

- **Linux native:** You can interact directly with the kernel driver via
  `/dev/usbtmcX`. For advanced users, *Linux-GPIB* also supports the
  adapter via a dedicated firmware variant.

- **python-usbtmc:** A great alternative if you want to avoid a VISA
  installation entirely. It is a bit more "hands-on" (manual
  configuration), but it supports the full command set of the adapter
  more reliably than PyVISA-py in many cases.

- **PyVISA-py:** A "VISA-free" Python backend. While popular, it
  currently has an incomplete USBTMC implementation (e.g., issues with
  version queries). Basic instrument communication works, but it may
  require workarounds for advanced features.

**Recommendation:** Use **R&S VISA** for a lightweight, professional
setup, or the **python-usbtmc** package if you strictly require a
driverless Python environment.

------------------------------------------------------------------------

**Can the CMU200 which uses GPIB subaddressing be used with this
adapter?**  
Yes, the CMU200 is supported and used too by me. USbGpib exposes the
first subaddresses which gives access to most features.

Also other devices with GPIB subaddressing are supported. UsbGpib will
always expose the firstly found subaddress over USBTMC.

------------------------------------------------------------------------

# References

<table>
<thead>
<tr>
<th colspan="2" style="text-align: center;"></th>
</tr>
</thead>
<tbody>
<tr>
<td style="text-align: left;">Issue reports and support</td>
<td style="text-align: left;"><span><a
href="https://github.com/xyphro/UsbGpib/issues"><span
class="uri">https://github.com/xyphro/UsbGpib/issues</span></a></span></td>
</tr>
<tr>
<td style="text-align: left;">Technical support and feature
requests</td>
<td style="text-align: left;"><span><a
href="mailto:xyphro@gmail.com"><span
class="uri">xyphro@gmail.com</span></a></span></td>
</tr>
<tr>
<td style="text-align: left;">Firmware download</td>
<td style="text-align: left;"><span><a
href="https://github.com/xyphro/UsbGpib/blob/master/SW/binaries/TestAndMeasurement.bin"><span
class="uri">https://github.com/xyphro/UsbGpib/blob/master/SW/binaries/TestAndMeasurement.bin</span></a></span></td>
</tr>
<tr>
<td style="text-align: left;">Tutorials</td>
<td style="text-align: left;"><span><a
href="https://github.com/xyphro/UsbGpib/blob/master/Tutorials/README.md"><span
class="uri">https://github.com/xyphro/UsbGpib/blob/master/Tutorials/README.md</span></a></span></td>
</tr>
</tbody>
</table>

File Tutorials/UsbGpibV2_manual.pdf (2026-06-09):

1

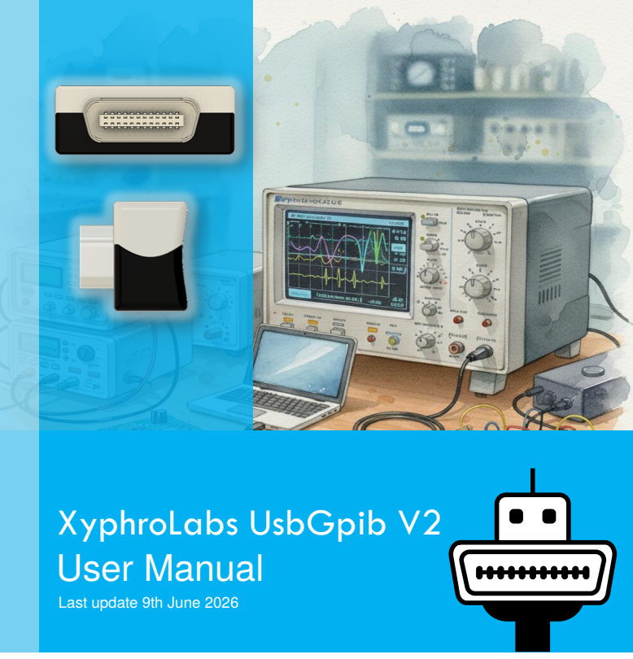
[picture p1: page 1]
XyphroLabs UsbGpib V2 User Manual

Last update 9th June 2026

# Contents

2

## 1 Introduction

The UsbGpib V2 is a compact, high-performance USB-to-GPIB adapter engineered from the ground up for seamless integration with modern and legacy test equipment.

Unlike clone devices, UsbGpib V2 delivers robust IEEE-488.1 and IEEE-488.2 compatibility, stable USBTMC operation, and a unique device identifier that ensures consistent VISA resource naming across systems - eliminating the need for manual remapping or COM port assignments.

Designed to match the physical footprint and cable path of traditional GPIB connectors, the adapter fits into all existing lab setups while offering significant advantages in space efficiency, cable management, and cross-platform support. Whether you’re automating instrument control on Windows, macOS, Linux, or FreeBSD, UsbGpib V2 provides plugand-play reliability without proprietary drivers.

With firmware upgradability, protocol-aware communication, and a focus on user-friendly integration, UsbGpib V2 is the ideal choice for engineers, researchers, and developers seeking a dependable GPIB interface that just works.

## 2 Advantages of UsbGpib V2 adapter

- Modern Connectivity: Bridges USB and IEEE 488 (GPIB) with full USBTMC protocol compliance
- Slim Design: Minimal depth of just 1.5cm allows instruments to be placed closer to walls or rack panels
- Cable Efficiency: Uses thin USB cables instead of bulky ”garden hose” GPIB cables, reducing clutter and improving portability
- Multi Adapter Support: Unique identifier per unit enables multiple adapters to be connected and operated reliably on the same PC
- No COM Ports: Avoids serial port mapping issues; Each adapter is consistently accessible with the same name across multiple PCs
- Transparent Operation: Plug into your instruments GPIB port and it behaves like a modern USB measurement device, including proper USB port deactivation when the instrument is powered off
- Controller Role: Optimized as a dedicated GPIB controller for one instrument per adapter, ensuring robust one to one communication and optimized cable management.
- Standards Compliance: Implements full IEEE-488.1 IEEE 488.2 controller support via USBTMC, including status byte reading, triggering, service requests, and termination settings
This document is part of Xyphro UsbGpib (https://github.com/xyphro/UsbGpib) project | Page — 3

- Software Compatibility: Works seamlessly with all standard VISA providers (NI VISA, Rohde & Schwarz VISA, Keysight VISA)
- Tool Integration: Fully compatible with LabVIEW, MATLAB, PyVISA, and PyVISA py for established and modern automation workflows
- Cross Platform Support: Operation across Windows, macOS, FreeBSD, and Linux
- German Engineering: Designed and developed in Germany over six years, extensively tested for robustness and compatibility with instruments from new to decades old
- Reliability: Built to ensure long automated measurement sequences complete without interruption
- Future Proof: Firmware is field upgradable and actively maintained, providing ongoing improvements and compatibility updates

## 3 Safety Precautions

To ensure reliable operation and long-term durability of the UsbGpib V2 adapter, please observe the following environmental and handling Guidelines

### 3.1 Operating Conditions

Temperature Range: 0°C to +50°C
Humidity: | 10% to 90% RH, non-condensing
Altitude: | Up to 2000m above sea level

### 3.2 Storage Conditions

Temperature Range: -20°C to +70°C
Humidity: | 5% to 95% RH, non-condensing

### 3.3 Moisture & Contaminants

- Avoid exposure to liquids, vapors or corrosive substances
- Do not operate in environments with condensation, high dust levels or chemical fumes

### 3.4 Electric Safety

- Do not expose to voltage levels above 6V
- Do not short circuit or connect to non IEEE488 / non-USB compliant ports
- Ensure proper grounding of connected instruments

### 3.5 Handling & Installation

- Do not bend or stress the USB or GPIB connectors during installation
- Avoid excessive force when plugging/unplugging
- Avoid direct sunlight
- Keep away from electrostatic discharge (ESD) sources; use ESD-safe handling procedures

## 4 Overview

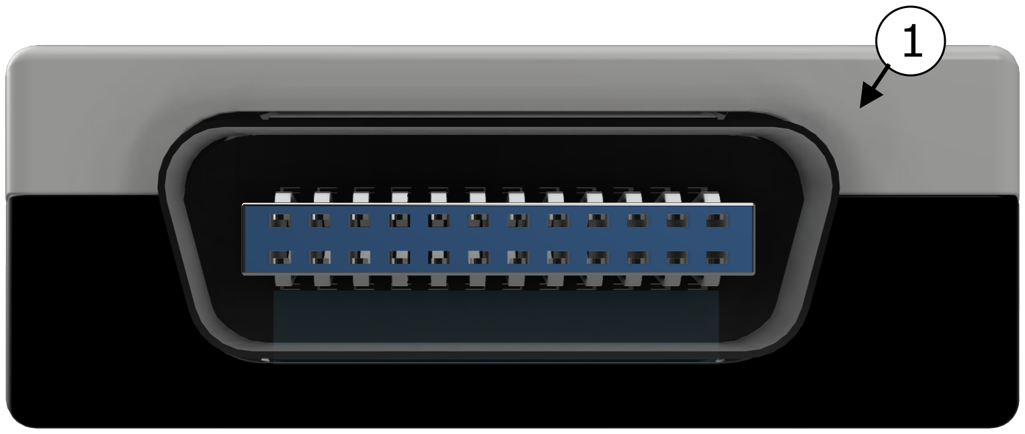
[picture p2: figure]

(1) GPIB connector - Plugs directly into your measurement equipments GPIB port.
(2) Status LED
(3) Firmware update button

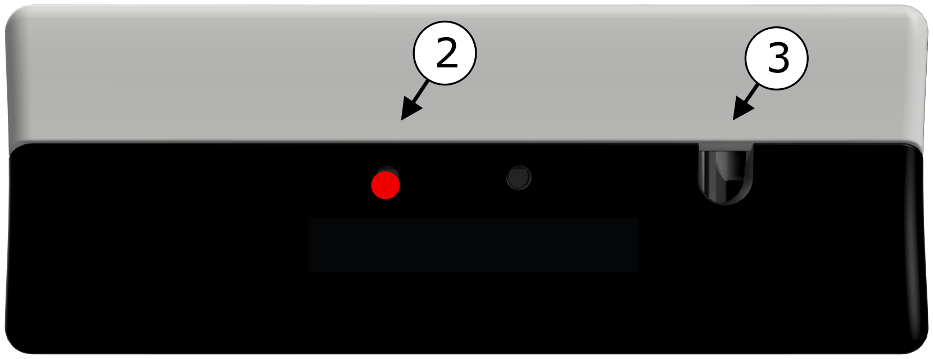
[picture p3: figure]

4
(4) USB-Type C connector - plug it with either a USB Type C to USB type A or USB type C to type C cable into your PC.

## 5 LED

The LED has multiple purposes as summarized in the table below.

Led blinking with a frequency of about 2
Hz. | The Adapter is connected to a USB
| port, but no GPIB device is found. Con-
| nect a GPIB measurement device to
| the GPIB port and ensure that GPIB is
| enabled in the instrument.
LED is continuously on.
| The GPIB device was identified, but no
| GPIB communication is executed from
| PC.
LED is flickering (mostly on, but sometimes off for short periods).

long short

Every time GPIB data is transferred from the PC or to the PC, the LED will be turned off for short periods of time. This indicates data exchange = activity. LED is always off.
The USB port is not connected to the PC, the PC powered off or the USB cable defect.

## 6 Using the adapter

To use the adapter, connect the USB-C connector with a USB cable to a PC.

The GPIB connector can be plugged directly into the measurement instrument, which you want to control. It can also connect via a GPIB cable if required due to setup constraints.

When the measurement equipment is turned on and if the GPIB port is enabled in the instrument, the adapter will enumerate on the PC as USBTMC class device.

Operating system specific instructions & tutorials are available under this link:

https://github.com/xyphro/UsbGpib/blob/master/Tutorials/README.md

Those tutorials explain how to ensure that a USB driver is installed and guide through the first setup up to the point where you can talk with the instrument.

Note: The UsbGpib Adapter does not enumerate on the PC, if it is not connected to a GPIB measurement device, which is powered and GPIB enabled.

## 7 Firmware update procedure

The UsbGpib V2 adapter comes preinstalled with a firmware. But as the firmware is actively maintained you might want to update the adapters firmware sooner or later. The UsbGpib V2 adapter allows for firmware updates. It requires the bootloader mode to be entered, followed by programming the firmware and power cycling the adapter.

Firmware images are distributed via GitHub:

https://github.com/xyphro/UsbGpib/tree/master/SW/binaries

to download, left-click on ”TestAndMeasurement.bin” file. After the new page loads, click on the RAW button on the top right side:

After downloading the file, rename it to FLASH.BIN. Ensure to use capital letters for the full filename during rename. Filenames with lowercase letters like ”Flash.bin”, ”flash.bin”, ”FLASH.bin” will result in the firmware update procedure not to work (but it won’t break the adapter).

After downloading the file, enter the bootloader:

- Connect the adapter to a PC via USB. The GPIB side can be left unconnected.
- Hold the button (3) down for a few seconds (use e.g. a pencil to push it), until the PC recognizes a memory stick device (USB flash or mass storage device).

A new drive appears on the PC:

Then open a command line and enter a command like the following:

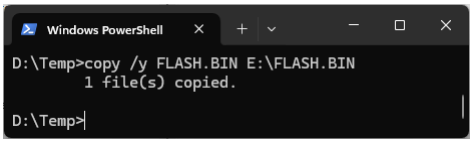
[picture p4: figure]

On Linux, use this command to transfer a firmware update, instead of using cp: dd if=TestAndMeasurement.bin of=/mnt/FLASH.BIN bs=512 conv=notrunc oflag=direct,sync

Adjust the file paths and drive letters to your actual system. When no error is shown, you can unplug USB (and GPIB) and reconnect to power cycle the adapter and use the new firmware.

Note: Drag and drop operation e.g. from Windows explorer does
not work. Ensure you use the command line method as described.

Note: In case the device behaves as if it is bricked (which can happen if you use cp under linux to reflash it), you can enter the bootloader mode by unplugging the USB cable, keeping the button pressed and connecting it again while holding the button.

## 8 Technical specifications

Item | Specification

USB power require-
ments | • 5V supply voltage nominal
- Valid supply voltage range: 4.5V to 5.5V
- 100mA current consumption
USB standard
- USB 1.1, USB 2.0, USB 3 and higher are supported with full speed mode

USB connector
- USB Type-C connector
- Compatible with USB-A by using a USB Type C to USB Type A cable
- Compatible with USB Type C to USB Type C cable. Supported IEEE-488
features | • IEEE-488.1, IEEE-488.2, HPIB, GPIB compatible
- Service request (reported using interrupt transfers)
- Device Clearing
- Trigger
- Status Byte read
- GPIB write, read and queries
(supports | talker | only, | listener | only | and
talker+listener instruments)
- Full timeout support for reliable operation
- All GPIB features are exposed using the exact US-BTMC equivalents for good compatibility

Item | Specification

Supported IEEE-488
device roles | • Controller
Operating Systems | • Windows
| • Linux, FreeBSD
| • Mac-OS
Dimensions | • Excluding GPIB connector:
| 60mm x 23mm x 15mm (Width x Height x Depth)
| • Including GPIB connector:
| 60mm x 23mm x 22mm (Width x Height x Depth)
Weight | • 30g

## 9 Frequently Asked Questions

Why doesn’t the adapter show up on my PC when I plug it in?
This is a feature called ”Ghost Mode.” The adapter only enumerates (becomes visible) on the PC if it is connected to a GPIB instrument that is powered on. This reduces device manager clutter when you have multiple adapters connected to instruments that are currently off.

The reason for this feature is to make an instrument behave like one with native USB interface and avoid seeing adapters on the PC with that you can’t communicate anyway as there is no measurement equipment connected.

What is the AutoID feature of UsbGpib V2?
AutoID is a feature where the adapter automatically queries the instrument for its identity (using *IDN?) and uses that information to create a unique VISA resource name. For very old instruments that do not support *IDN?, this feature should be disabled to avoid errors. When Auto ID is off, the Visa ressource name is constructed out of the GPIB address of the instrument and a unique serial number of the GPIB adapter.

What are the AutoID timing options?
When the AutoID feature is enabled there are different delay options. This delay specifies how long the adapter waits after instrument turnon before executing the *IDN? query for the AutoID feature. While 5s works for each instrument, some instruments require a setting to higher number which is exposed by the other AutoID settings. AutoID is a non-volatile setting which is permanently stored in the MCUs eeprom. UsbGpibGui:
- AutoID ON: The adapter waits 5 seconds after detecting a powered GPIB instrument before performing the identification scan *IDN?.

- AutoID SLOW: Increases the initial waiting period to 15 seconds before the scan begins.
- AutoID SLOWEST: Designed for instruments with very long boot sequences, this setting waits 30 seconds before attempting to communicate on the GPIB side.
- AutoID OFF: Disables the automatic identification query entirely. This is essential for older, non-SCPI instruments that do not support the *IDN? query and might return errors or lock up if they receive it.

Tip: Turn AutoID OFF for older non SCPI compliant instruments to avoid that they start up with an Error. To change the AutoID settings you can use e.g. the UsbGpibGui in the UsbGpib SW folder for Windows or NiceGui for Linux. Note that UsbGpib GUI requires a Visa installation.

How do I set Read Termination?
It is best to use standard VISA attributes:
- Set VI ATTR TERMCHAR EN to 1.
- Set VI ATTR TERMCHAR to 0x0A (or any other ASCII character).

With firmware version ≥ 2.2 you can set any read termination character you like, from ASCII code 0 to 255. This enables instruments to react on EOT, CR, LF or any other character like e.g. ’,’ for easier parsing of input data. Independent of the set termination character setting the instrument will always react on the GPIB EOI as termination of a read query.

When read termination is turned off, the read termination is EOI only.

Is the UsbGpib adapter a clone of an existing commercial adapter?
No. This is a common and important misconception. The UsbGpib adapter is a completely original, open-source hardware and software project and does not copy commercial adapters. It works for that reasons without risk of getting blocked or locked out in future.
- Unique Identity: Unlike the many inexpensive adapters found on online marketplaces, this is not a counterfeit clone of National Instruments (NI), Keysight or other hardware.
- Safe to Use: Because it is not a clone, it is safe from ”driver sabotage.” Vendor software updates (like those from NI-VISA) often detect and disable counterfeit hardware; since this adapter uses its own independent firmware and identity, it remains fully functional and stable regardless of official driver updates.

- Standard Compliance: Instead of mimicking a proprietary device, it implements the standard USBTMC-USB488.2 protocol. This allows it to ”nicely integrate” into any VISA environment by following industry standards rather than exploiting a specific manufacturer’s driver.

In short: It is an independent, professional-grade tool designed to coexist peacefully within the ecosystem of your choice.

Does it support Service Requests (SRQ)?
Yes, the adapter actively pushes SRQ signaling to the PC via an interrupt pipe, as mandated by the USBTMC 488.2 standard. This means your software does not need to poll for status continuously.

Can I use it with Linux?
Yes, it can be used either as a standard USBTMC device or through Linux-GPIB for advanced features like controlling multiple instruments with a single adapter. In case you want to use Linux-GPIB, have a look here and search for ”xyphro” for further instructions: https://linux-gpib.sourceforge.io/doc html/supported-hardware.html (https://linux-gpib.sourceforge.io/doc_html/supported-hardware.html)

Do I really need to use a VISA library?
Technically, no-but it is highly recommended. Because the adapter follows the standard USBTMC protocol, it is natively recognized by modern operating systems. Visa, while it seems like an ”old-school concept” is a quite convinient tool to enable access to instruments over multiple different interfaces with a common interface.

I started e.g. by controlling only USBTMC instruments and made a dedicated solution for that without visa, but when I later wanted to control GPIB instruments and Ethernet based instruments in the same setup, that ”island solution” concept breaked and I started looking seriously into Visa and saw the clear benefits. Don’t get shocked by Gigabytes of Visa installation - there are smaller Visas available like e.g. R&S Visa. Lean and mean and available for Mac OS, Windows, Linux and even Raspberry PI with the same application level interface across those operating systems. You also get a very stable tested solution for your instrument access and can focus on the real measurement task.

- With VISA: Libraries like R&S VISA or NI-VISA provide a unified API. This is the most stable path for tools like LabVIEW or standard PyVISA.
- Linux native: You can interact directly with the kernel driver via /dev/usbtmcX. For advanced users, Linux-GPIB also supports the adapter via a dedicated firmware variant.
- python-usbtmc: A great alternative if you want to avoid a VISA installation entirely. It is a bit more ”hands-on” (manual configuration), but it supports the full command set of the adapter more reliably than PyVISA-py in many cases.
- PyVISA-py: A ”VISA-free” Python backend. While popular, it currently has an incomplete USBTMC implementation (e.g., issues with version queries). Basic instrument communication works, but it may require workarounds for advanced features.

Recommendation: Use R&S VISA for a lightweight, professional setup, or the python-usbtmc package if you strictly require a driverless Python environment.

Can the CMU200 which uses GPIB subaddressing be used with this adapter? Yes, the CMU200 is supported and used too by me. USbGpib exposes the first subaddresses which gives access to most features.

Also other devices with GPIB subaddressing are supported. UsbGpib will always expose the firstly found subaddress over USBTMC.

## 10 References

Issue reports and support

https://github.com/xyphro/UsbGpib/issues

Technical support and
feature requests

xyphro@gmail.com

Firmware download | https://github.com/ xyphro/UsbGpib/blob/master/SW/binaries/ TestAndMeasurement.bin (https://github.com/xyphro/UsbGpib/blob/master/SW/binaries/TestAndMeasurement.bin)
Tutorials | https : / / github . com / xyphro / UsbGpib / blob / master / Tutorials / README.md (https://github.com/xyphro/UsbGpib/blob/master/Tutorials/README.md)

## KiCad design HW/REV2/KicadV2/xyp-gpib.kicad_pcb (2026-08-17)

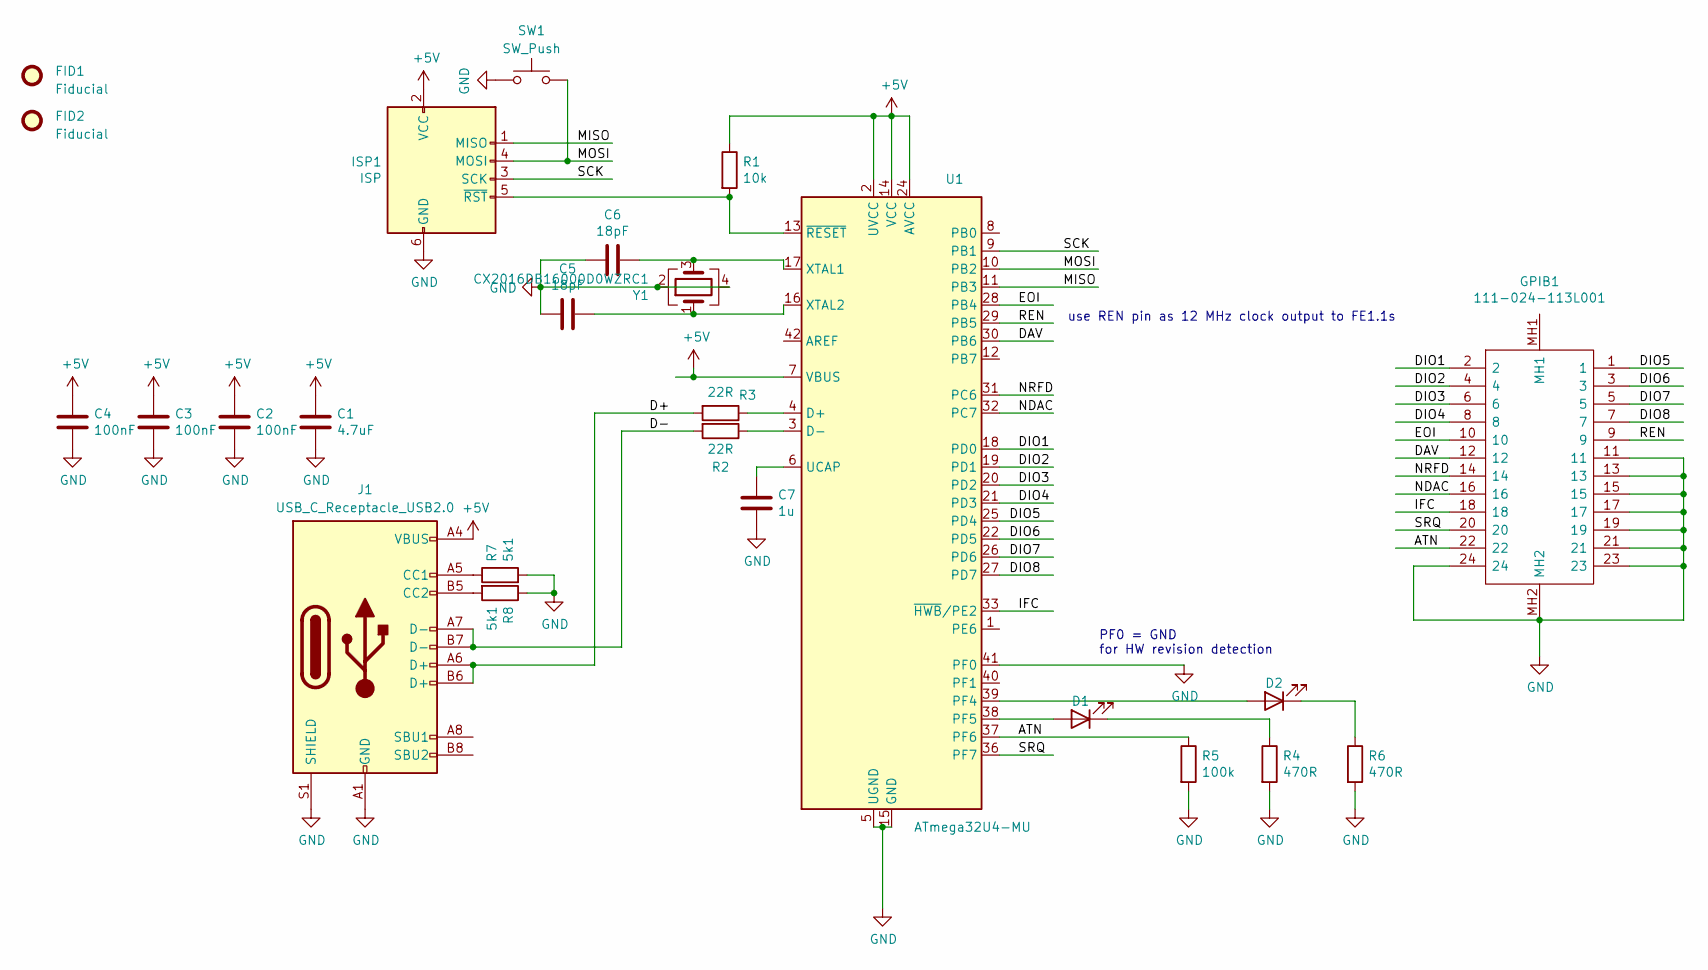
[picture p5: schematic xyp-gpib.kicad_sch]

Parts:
C1: 4.7uF; C_0805_2012Metric
C2, C3, C4: 100nF; C_0603_1608Metric
C5, C6: 18pF; C_0603_1608Metric
C7: 1u; C_0603_1608Metric
D1, D2: LED; LED_0805_2012Metric
FID1, FID2: Fiducial; Fiducial_0.5mm_Mask1mm
GPIB1: 111-024-113L001; 112024113R001; Manufacturer_Part_Number 112-024-113R001; Mouser Part Number 636-112-024-113R001
ISP1: ISP; EdgeProg
J1: USB_C_Receptacle_USB2.0; USB_C_Receptacle_XKB_U262-16XN-4BVC11
R1: 10k; R_0603_1608Metric
R2, R3: 22R; R_0603_1608Metric
R4, R6: 470R; R_0603_1608Metric
R5: 100k; R_0603_1608Metric
R7, R8: 5k1; R_0603_1608Metric
SW1: SW_Push; SW_Tactile_SPST_NO_Straight_CK_PTS636Sx25SMTRLFS
U1: ATmega32U4-MU; QFN-44-1EP_7x7mm_P0.5mm_EP5.2x5.2mm
Y1: CX2016DB16000D0WZRC1; Crystal_SMD_2016-4Pin_2.0x1.6mm

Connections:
+5V: C1.1, C2.1, C3.1, C4.1, ISP1.2 (VCC), J1.A4 (VBUS), J1.A9 (VBUS), J1.B4 (VBUS), J1.B9 (VBUS), R1.1, U1.2 (UVCC), U1.7 (VBUS), U1.14 (VCC), U1.24 (AVCC), U1.34 (VCC), U1.44 (AVCC)
/ATN: GPIB1.22, R5.1, U1.37 (PF6)
/D+: J1.A6 (D+), J1.B6 (D+), R3.2
/D-: J1.A7 (D-), J1.B7 (D-), R2.2
/DAV: GPIB1.12, U1.30 (PB6)
/DIO1: GPIB1.2, U1.18 (PD0)
/DIO2: GPIB1.4, U1.19 (PD1)
/DIO3: GPIB1.6, U1.20 (PD2)
/DIO4: GPIB1.8, U1.21 (PD3)
/DIO5: GPIB1.1, U1.25 (PD4)
/DIO6: GPIB1.3, U1.22 (PD5)
/DIO7: GPIB1.5, U1.26 (PD6)
/DIO8: GPIB1.7, U1.27 (PD7)
/EOI: GPIB1.10, U1.28 (PB4)
/IFC: GPIB1.18, U1.33 (~HWB/PE2)
/MISO: ISP1.1 (MISO), U1.11 (PB3)
/MOSI: ISP1.4 (MOSI), SW1.2, U1.10 (PB2)
/NDAC: GPIB1.16, U1.32 (PC7)
/NRFD: GPIB1.14, U1.31 (PC6)
/REN: GPIB1.9, U1.29 (PB5)
/SCK: ISP1.3 (SCK), U1.9 (PB1)
/SRQ: GPIB1.20, U1.36 (PF7)
GND: C1.2, C2.2, C3.2, C4.2, C5.2, C6.2, C7.2, GPIB1.11, GPIB1.13, GPIB1.15, GPIB1.17, GPIB1.19, GPIB1.21, GPIB1.23, GPIB1.24, GPIB1.MH2, ISP1.6 (GND), J1.A1 (GND), J1.A12 (GND), J1.B1 (GND), J1.B12 (GND), J1.S1 (SHIELD), R4.2, R5.2, R6.2, R7.2, R8.1, SW1.1, U1.5 (UGND), U1.15 (GND), U1.23 (GND), U1.35 (GND), U1.41 (PF0), U1.43 (GND), U1.45 (GND), Y1.2, Y1.4
unnamed: D1.2 (A), U1.38 (PF5)
unnamed: D1.1 (K), R4.1
unnamed: D2.2 (A), U1.39 (PF4)
unnamed: D2.1 (K), R6.1
unnamed: ISP1.5 (~RST), R1.2, U1.13 (~RESET)
unnamed: J1.A5 (CC1), R7.1
unnamed: J1.B5 (CC2), R8.2
unnamed: R3.1, U1.4 (D+)
unnamed: R2.1, U1.3 (D-)
unnamed: C7.1, U1.6 (UCAP)
unnamed: C6.1, U1.17 (XTAL1), Y1.3
unnamed: C5.1, U1.16 (XTAL2), Y1.1

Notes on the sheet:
PF0 = GND for HW revision detection
use REN pin as 12 MHz clock output to FE1.1s

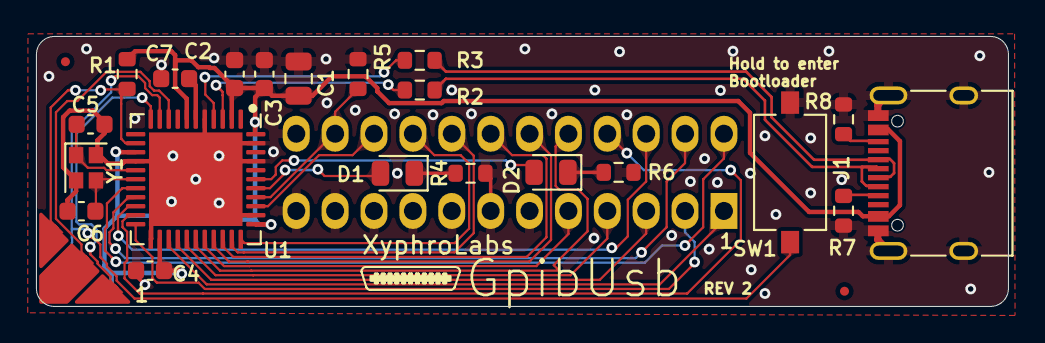
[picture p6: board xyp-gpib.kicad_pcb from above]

Board: 2 copper layers, 54.0 x 15.0 mm, 25 parts (1 on the bottom side), 35 nets.
